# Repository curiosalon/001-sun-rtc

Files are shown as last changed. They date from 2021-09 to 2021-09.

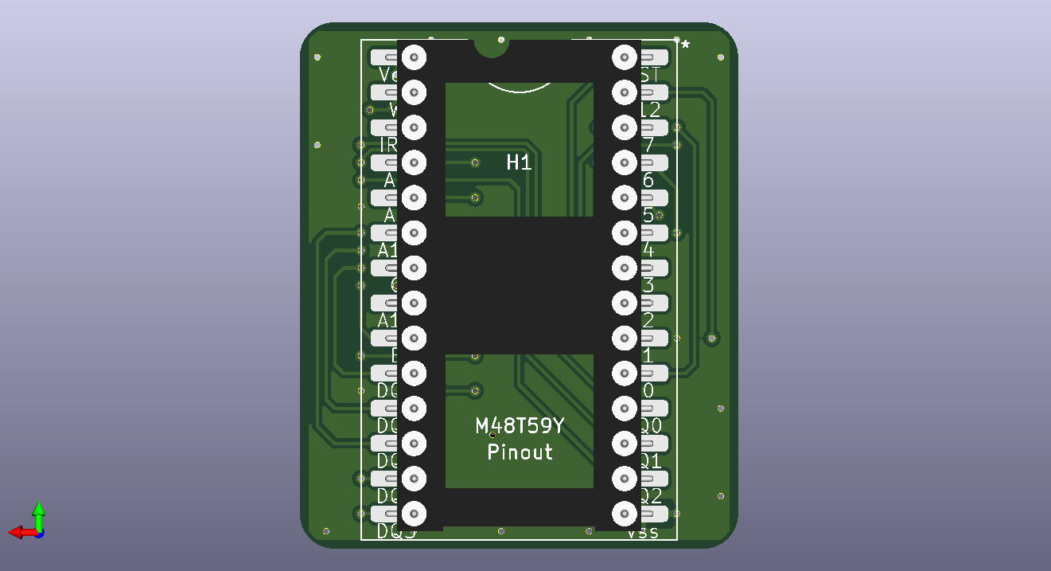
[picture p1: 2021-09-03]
images/NVRTC-rev1-back.png

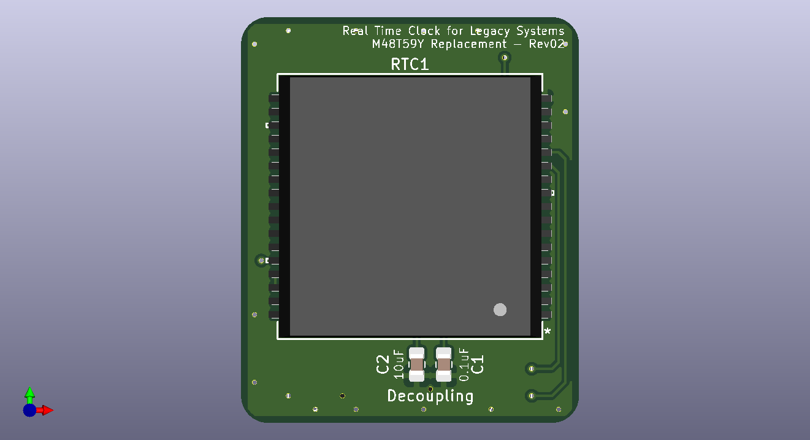
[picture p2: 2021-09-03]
images/NVRTC-rev1-front.png

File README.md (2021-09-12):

# NVRAM/IDPROM Replacement for M48T59Y Real Time Clock

This project intends to design a timing and register compatible module
to replace the now obsoleted M48T59Y realtime clock chip used in
the following Sun Microsystems computers:

| WORKSTATION SYSTEM | HOSTID | COMPONENT | SUN PART |
|:---|:---|:---|:---|
| **Sun Blade 100**  | 8xxxxxxx | 48T59 | f100-6889 |
| **Sun Blade 150**  | 83xxxxxx | 48T59 | f100-6889 |
| **Ultra 1** | 80xxxxxx | 48T59 | 525-1430 |
| **Ultra 2** | 80xxxxxx | 48T59 | 525-1417 |
| **Ultra 5/10** | 8xxxxxxx | 48T59 | 525-1430 |
| **Ultra 30** | 80xxxxxx | 48T59 | 525-1430 |
| **Ultra 60** | 8xxxxxxx | 48T59 | 525-1430 |
| **Ultra 80** | 8xxxxxxx | 48T59 | 525-1785 |

| WORKSTATION SYSTEM | HOSTID | COMPONENT | SUN PART |
|:---|:---|:---|:---|
| **E220R** | 8xxxxxxx | 48T59 | 525-1430 |
| **E250** | 83xxxxxx | 48T59 | 525-1726 |
| **E420R** | 80xxxxxx | 48T59 | 525-1785 |
| **E450** | 80xxxxxx | 48T59 | 525-1673 |
| **Ex000 Clock** | 8xxxxxxx | 48T59 | f100-4007 |
| **Ex000 I/O** | 80xxxxxx | 48T59 | f100-4007 |
| **Fx800 Sys Cont** | 8xxxxxxx | 48T59 | f100-4007 |
| **Ex900 Sys Cont** | 8xxxxxxx | 48T59 | 100-7822 |

| TELCO SYSTEM | HOSTID | COMPONENT | SUN PART |
|:---|:---|:---|:---|
| **Netra 120** | --- | 48T59 | 100-6889 |
| **Sun Fire V120** | --- | 48T59 | 100-6889 |
| **Netra AX1105** | 83xxxxxx | 48T59 | ? |
| **SPARCengine CP1400** | 8xxxxxxx | 48T59 | 525-1803 |
| **Netra CP2140** | 83xxxxxx | 48T59 | 100-5876 |
| **Netra CP2140** | 83xxxxxx | 48T59 | 100-5893 |
| **Netra T1 AC200/DC200** | --- | 48T59 | 100-6889 |

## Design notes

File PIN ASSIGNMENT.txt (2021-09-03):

PIN ASSIGNMENT
DS1554X -> M48T59
=======================
PIN   DS1554P   DS1554
=======================
1        26       1
2        NC       NC
3        NC       2
4        1        21
5        28       5
6        27       6
7        22       7
8        20       8
9        19       9
10       18       10
11       17       28
12       16       28
13       15       11
14       13       12
15       12       13
16       11       14
17       14       15
18       28       16
19       28       17
20       10       18
21       9        19
22       8        20
23       7        25
24       6        22
25       5        24
26       4        3
27       3        4
28       25       23
29       24       27
30       21       26
31       23       NC
32       2        28
33       NC       -
34       NC       -

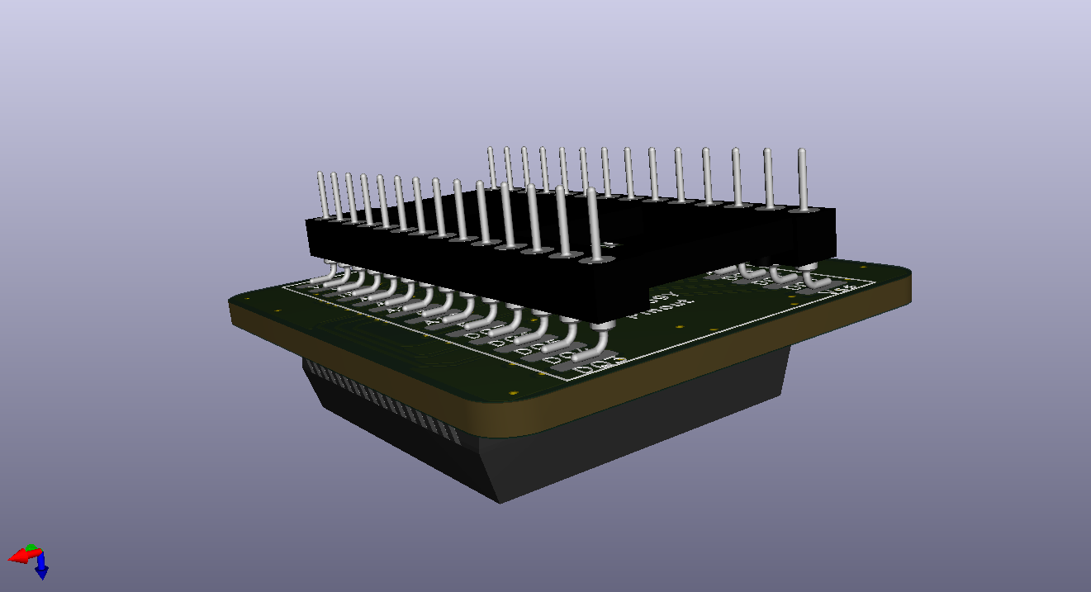
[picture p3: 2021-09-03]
images/NVRTC-rev1-perspective.png

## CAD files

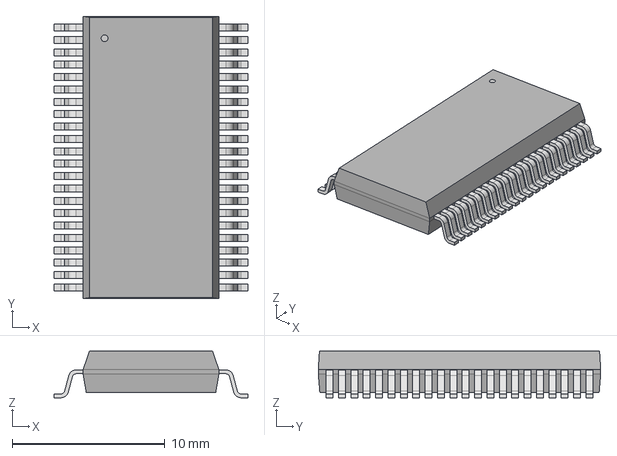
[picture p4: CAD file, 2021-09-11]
3d_models/SOH44_STM.step
12.7 x 18.5 x 3.05 mm

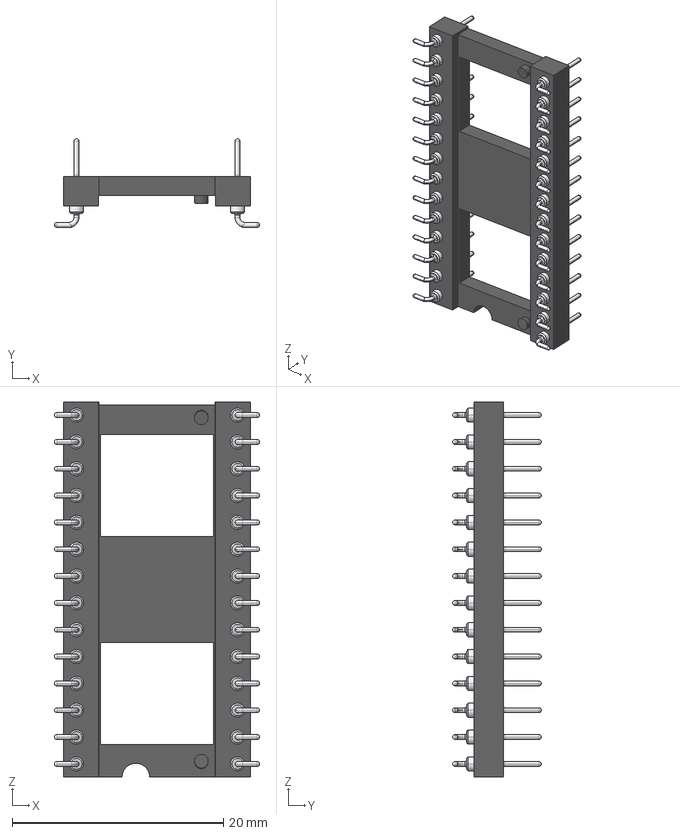
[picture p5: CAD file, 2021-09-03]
3d_models/dil_socket_150-80-628-00-106161.stp
19.4 x 8.40 x 35.5 mm

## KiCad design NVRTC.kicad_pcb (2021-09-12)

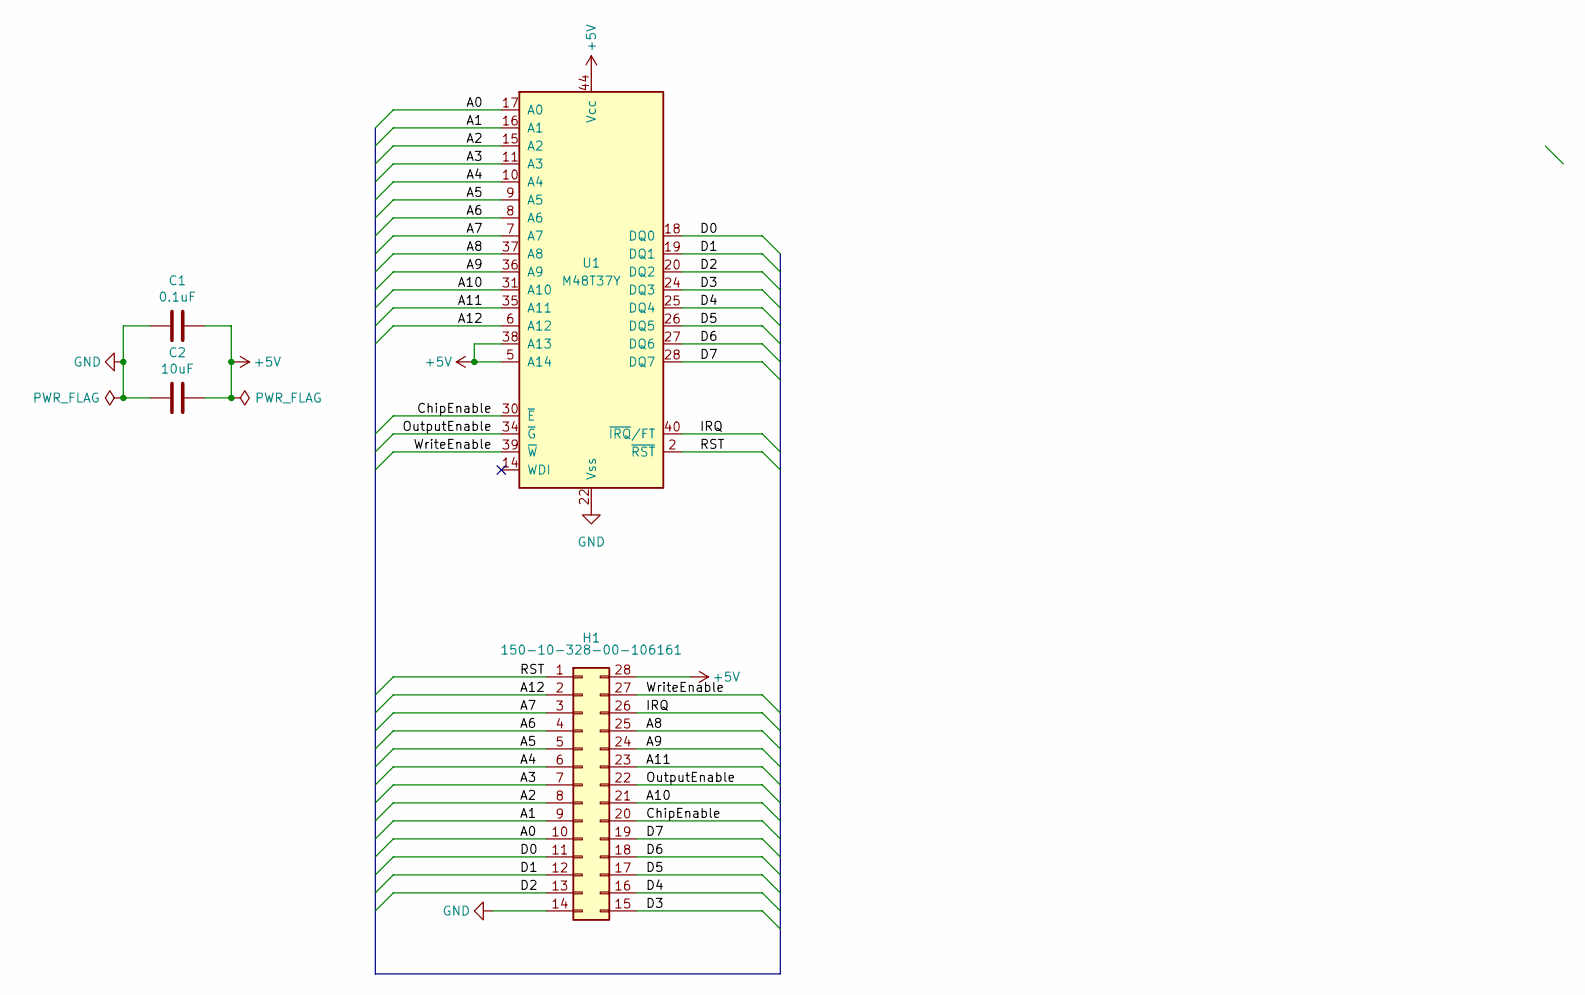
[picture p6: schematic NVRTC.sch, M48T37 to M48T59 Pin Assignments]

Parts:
C1: 0.1uF; C_0805_2012Metric_Pad1.18x1.45mm_HandSolder
C2: 10uF; C_0805_2012Metric_Pad1.18x1.45mm_HandSolder
H1: 150-10-328-00-106161; DIL28-M48T59Y
U1: M48T37Y; STM-SOH-44

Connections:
+5V: C1.1, C2.1, H1.28, U1.5 (A14), U1.38 (A13), U1.44 (Vcc)
/A0: H1.10, U1.17 (A0)
/A1: H1.9, U1.16 (A1)
/A2: H1.8, U1.15 (A2)
/A3: H1.7, U1.11 (A3)
/A4: H1.6, U1.10 (A4)
/A5: H1.5, U1.9 (A5)
/A6: H1.4, U1.8 (A6)
/A7: H1.3, U1.7 (A7)
/A8: H1.25, U1.37 (A8)
/A9: H1.24, U1.36 (A9)
/A10: H1.21, U1.31 (A10)
/A11: H1.23, U1.35 (A11)
/A12: H1.2, U1.6 (A12)
/ChipEnable: H1.20, U1.30 (~E)
/D0: H1.11, U1.18 (DQ0)
/D1: H1.12, U1.19 (DQ1)
/D2: H1.13, U1.20 (DQ2)
/D3: H1.15, U1.24 (DQ3)
/D4: H1.16, U1.25 (DQ4)
/D5: H1.17, U1.26 (DQ5)
/D6: H1.18, U1.27 (DQ6)
/D7: H1.19, U1.28 (DQ7)
/IRQ: H1.26, U1.40 (~IRQ~/FT)
/OutputEnable: H1.22, U1.34 (~G)
/RST: H1.1, U1.2 (~RST~)
/WriteEnable: H1.27, U1.39 (~W)
GND: C1.2, C2.2, H1.14, U1.22 (Vss)

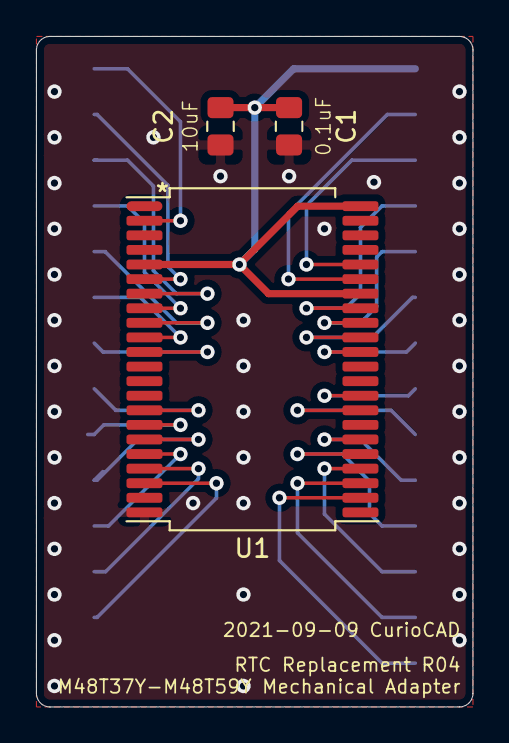
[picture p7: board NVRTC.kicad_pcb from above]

Board: 2 copper layers, 24.2 x 37.2 mm, 4 parts (1 on the bottom side), 28 nets.

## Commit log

2021-09-03 Configure project in git
    [21-0246_PC22_MXM.step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]
2021-09-11 Bump to Revision 4 Convert clock to M48T37 away from DS1554 Convert wiring to bus since all connections are labeled M48T37 Footprint is untested since manufacturer footprint is unavailable
    [SOH44_STM.step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]
2021-09-12 Rev 4
    [21-0246_PC22_MXM.step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]
